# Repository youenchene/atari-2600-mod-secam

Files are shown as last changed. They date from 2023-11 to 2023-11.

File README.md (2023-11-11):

# Atari 2600 Mod SECAM

This project is documentation and gerber files (files to create PCBs) to get SCART SECAM RGB Video Output of your Atari 2600.

No more blury, awful soup of pixels. Welcome clean big early 80's pixel.

## Disclaimer

All credits remains for Mr Eddy works which you can find here : http://eddystoys.blogspot.com/2014/08/atari-2600.html

If you want a ready to use kit you can buy it here :

- PCB Only : https://klydes-korner.site/en/product/convertisseur-video-rgb-atari-2600-secam-pcb-seul/
- Kit to solder : https://klydes-korner.site/en/product/convertisseur-video-rgb-atari-2600-secam-kit/
- Ready To Use : https://klydes-korner.site/en/product/convertisseur-video-rgb-atari-2600-secam/

You also have  CMS version of the PCB from the Modder Brothers : https://gitlab.com/modderbrothers/a2600-secam-rgb

## Before and After

### Before

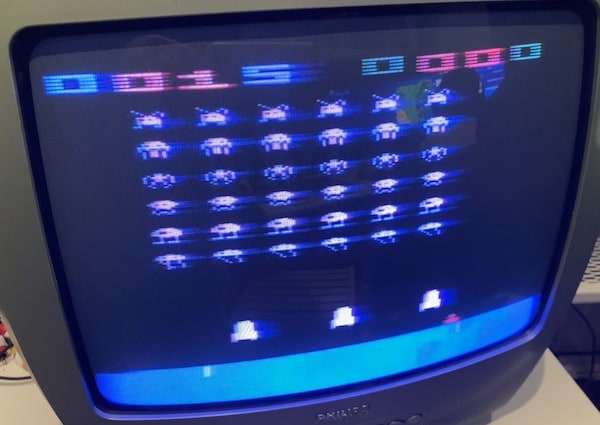
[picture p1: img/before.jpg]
Space Invader, all blury, I want to puke


### After

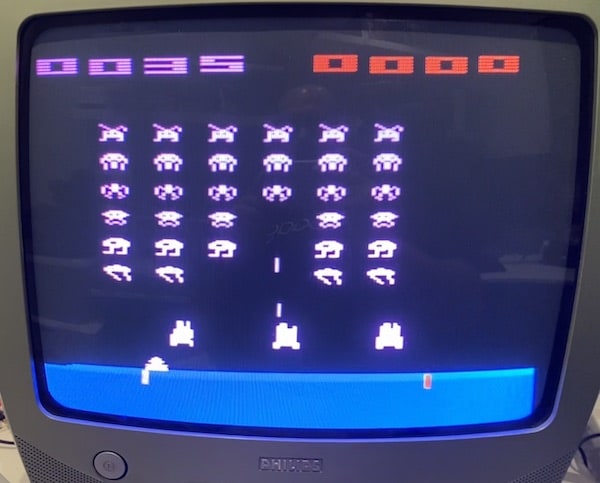
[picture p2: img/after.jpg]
Space Invader, clean pixels, kids let's play!


## Warning

It need soldering on your Atari 2600, I would say it's medium skill soldering, it's not so difficult.

Be aware you can damage your Atari 2600 and it's your responsability.

## How to build

### PCB

Go to PCBWay, Fast PCB, JL PCB or other supplier using this zip file : [gerber/AtariSecam.zip](gerber/AtariSecam.zip).

If your lazy your use my PCBWay project and make your order from here : https://www.pcbway.com/project/shareproject/Atari_2600_Video_Mod_SECAM_857de2b7.html
## Components

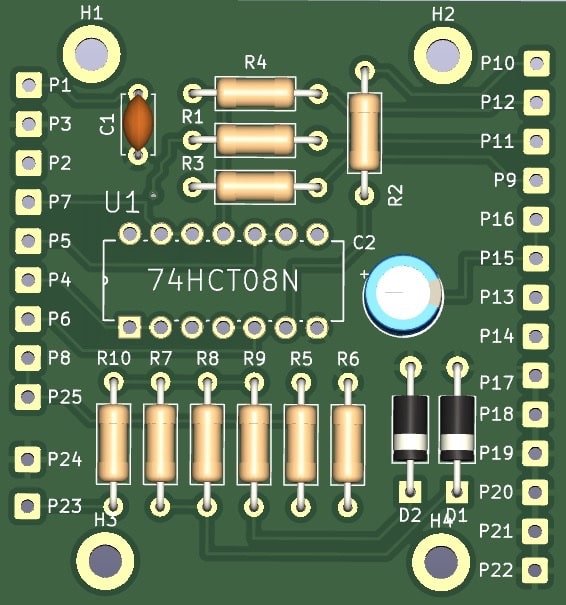
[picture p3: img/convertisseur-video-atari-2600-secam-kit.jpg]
PCB View


| Reference | Value | Qté |
|---|---|---|
| C1 | 100nF | 1 |
| C2 | 47uF | 1 |
| D1 | D_Zener 2.7v | 1 |
| D2 | D_Zener 10v | 1 |
| R1-R4 | 470R | 4 |
| R5, R10 | 1K | 2 |
| R6 | 1k | 1 |
| R7, R8 | 300R | 2 |
| R9 | 200R | 1 |
| U1 | 74HCT08N | 1 |

You also need :
- a scart cable from garage sales or "Foire à tout" like we say in Normandy.
- wiring cable.

## Wiring

### SCART

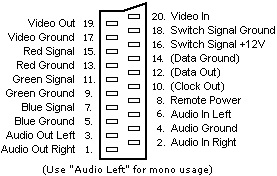
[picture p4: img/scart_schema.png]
SCART Schema SCART Schema


| PCB | SCART |
|---|---|
| P9 | SCART R (15) |
| P10 | SCART G (11) |
| P11 | SCART B (7) |
| P12 | SCART Synchro (20) |
| P13 | SCART Com Slow (8) |
| P14 | SCART Com Fast (16) |
| P15 | SCART Audio R (2) |
| P16 | SCART Audio L (6) |
| P17 | SCART Ground R (13) |
| P18 | SCART Ground G (9) |
| P19 | SCART Ground B (5) |
| P20 | SCART Ground Sync (17) |
| P21 | SCART Ground Audio (4) |
| P22 | SCART Shield (21) |

If you get a male/male scart cable that you cut of beware that the wiring between audio (2,4 - 1,5) and synchro (20-19) is inverted (input to output), always check this is the right pin on the scart you will plug. I lost 2 hours to diagnose and rewire.

### Atari 2600

| Mod PCB | Comments | Atari 2600 PCB |
|---|---|---|
| P1 | +5v | Power regulator Right one - green wire on the photo |
| P2 | +9,5v | Power regulator left one - red wire on the photo |
| P3 | Ground | Power regulator middle one - black wire on the photo |
| P4 | TIA LUM 0 | C0111903/UM6521* (Pal) : 7  <br/>  C01014444D (NTSC) : 2 |
| P5 | TIA LUM 1 | C0111903/UM6521* (Pal) : 5 <br/>  C01014444D (NTSC) : 8 |
| P6 | TIA LUM 2 | C0111903/UM6521* (Pal) : 6 <br/>  C01014444D (NTSC) : 5 |
| P7 | TIA Synchro | C0111903/UM6521* (Pal) : 2 <br/>  C01014444D (NTSC) : 7 |
| P8 | TIA Audio | C0111903/UM6521* (Pal) : 13  <br/>  C01014444D (NTSC) : 13 |
| P25 | Iso potential P8 | Not connected |

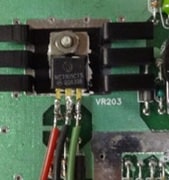
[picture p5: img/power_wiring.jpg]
Wiring for P1, P2, P3, All credits to Mr Eddy


_Wiring for P1, P2, P3, All credits to Mr Eddy_

To identify better the wiring on the Atari 2600 : 

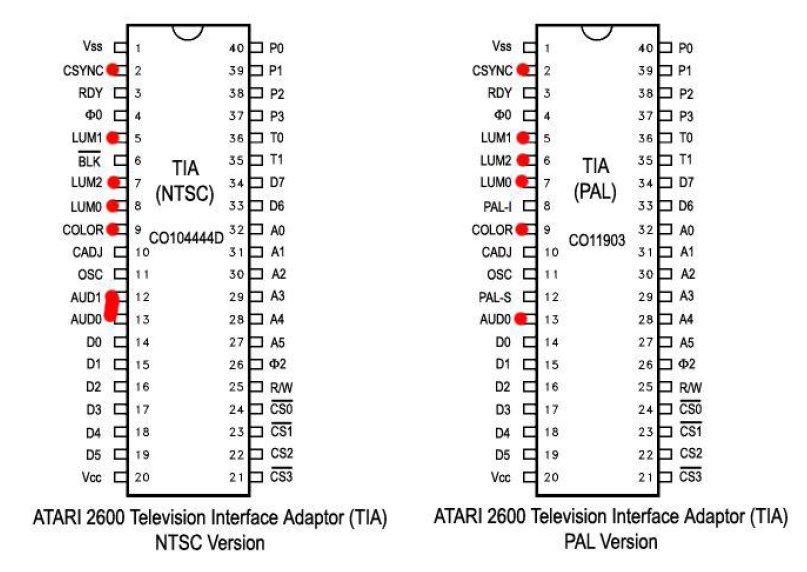
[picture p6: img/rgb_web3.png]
Atari 2600 TIA Wiring, all credits to Mr Eddy

_All credits to Mr Eddy_

Note that the C011903 can have other name, on mine it was an UM6521P1, it exactly the same wiring as the C011903.

On the table, the C01014444D it's the same chip but for NTSC Atari 2600. 

### LED - Optional

Optional, you can plug a 10mA or 20mA LED on P23 and P24.

P23 is + wiring (long pin).

P24 is ground wiring (short pin).

## Video Tutorials

(French) CabriDIY / [Atari 2600] Construction du kit RGB pour Atari 2600 https://youtu.be/S6Wm6l0JoSQ?si=zYLoU-hGtrezSI1l

(French) CabriDIY / [Atari 2600] Installation d'un mod RGB sur une Atari 2600 (prise péritel) https://youtu.be/MnF89gb17LY?si=qCZCWdnxvj2ZiaQF

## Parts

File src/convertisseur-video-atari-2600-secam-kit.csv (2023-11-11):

Reference | Value | Footprint | Datasheet | Availability | Check_prices | Description | MF | MP | MPN | OC_FARNELL | OC_NEWARK | PACKAGE | Package | Price | SUPPLIER | SnapEDA_Link | Qté
C1 | 100nF | Capacitor_THT:C_Disc_D4.7mm_W2.5mm_P5.00mm | ~ |  |  |  |  |  |  |  |  |  |  |  |  |  | 1
C2 | 47uF | Capacitor_THT:CP_Radial_D6.3mm_P2.50mm | ~ |  |  |  |  |  |  |  |  |  |  |  |  |  | 1
D1 | D_Zener 2.7v | Diode_THT:D_A-405_P10.16mm_Horizontal | ~ |  |  |  |  |  |  |  |  |  |  |  |  |  | 1
D2 | D_Zener 10v | Diode_THT:D_A-405_P10.16mm_Horizontal | ~ |  |  |  |  |  |  |  |  |  |  |  |  |  | 1
H1-H4 | MountingHole | MountingHole:MountingHole_2.7mm_M2.5_DIN965_Pad | ~ |  |  |  |  |  |  |  |  |  |  |  |  |  | 4
P1-P8, P23-P25 | Conn_01x01_Pin | Connector_Wire:SolderWire-0.5sqmm_1x01_D0.9mm_OD2.1mm | ~ |  |  |  |  |  |  |  |  |  |  |  |  |  | 11
P9 | SCART R (15) | Connector_Wire:SolderWire-0.5sqmm_1x01_D0.9mm_OD2.1mm | ~ |  |  |  |  |  |  |  |  |  |  |  |  |  | 1
P10 | SCART V (11) | Connector_Wire:SolderWire-0.5sqmm_1x01_D0.9mm_OD2.1mm | ~ |  |  |  |  |  |  |  |  |  |  |  |  |  | 1
P11 | SCART B (7) | Connector_Wire:SolderWire-0.5sqmm_1x01_D0.9mm_OD2.1mm | ~ |  |  |  |  |  |  |  |  |  |  |  |  |  | 1
P12 | SCART Synchro (20) | Connector_Wire:SolderWire-0.5sqmm_1x01_D0.9mm_OD2.1mm | ~ |  |  |  |  |  |  |  |  |  |  |  |  |  | 1
P13 | SCART Com Lente (8) | Connector_Wire:SolderWire-0.5sqmm_1x01_D0.9mm_OD2.1mm | ~ |  |  |  |  |  |  |  |  |  |  |  |  |  | 1
P14 | SCART Com Rapide (16) | Connector_Wire:SolderWire-0.5sqmm_1x01_D0.9mm_OD2.1mm | ~ |  |  |  |  |  |  |  |  |  |  |  |  |  | 1
P15 | SCART_Audio D (2) | Connector_Wire:SolderWire-0.5sqmm_1x01_D0.9mm_OD2.1mm | ~ |  |  |  |  |  |  |  |  |  |  |  |  |  | 1
P16 | SCART Audio G (6) | Connector_Wire:SolderWire-0.5sqmm_1x01_D0.9mm_OD2.1mm | ~ |  |  |  |  |  |  |  |  |  |  |  |  |  | 1
P17 | SCART Masse R (13) | Connector_Wire:SolderWire-0.5sqmm_1x01_D0.9mm_OD2.1mm | ~ |  |  |  |  |  |  |  |  |  |  |  |  |  | 1
P18 | SCART Masse V (9) | Connector_Wire:SolderWire-0.5sqmm_1x01_D0.9mm_OD2.1mm | ~ |  |  |  |  |  |  |  |  |  |  |  |  |  | 1
P19 | SCART Masse B (5) | Connector_Wire:SolderWire-0.5sqmm_1x01_D0.9mm_OD2.1mm | ~ |  |  |  |  |  |  |  |  |  |  |  |  |  | 1
P20 | SCART Masse Sync (17) | Connector_Wire:SolderWire-0.5sqmm_1x01_D0.9mm_OD2.1mm | ~ |  |  |  |  |  |  |  |  |  |  |  |  |  | 1
P21 | SCART Masse Audio | Connector_Wire:SolderWire-0.5sqmm_1x01_D0.9mm_OD2.1mm | ~ |  |  |  |  |  |  |  |  |  |  |  |  |  | 1
P22 | SCART Shield | Connector_Wire:SolderWire-0.5sqmm_1x01_D0.9mm_OD2.1mm | ~ |  |  |  |  |  |  |  |  |  |  |  |  |  | 1
R1-R4 | 470R | Resistor_THT:R_Axial_DIN0207_L6.3mm_D2.5mm_P10.16mm_Horizontal | ~ |  |  |  |  |  |  |  |  |  |  |  |  |  | 4
R5, R10 | 1K | Resistor_THT:R_Axial_DIN0207_L6.3mm_D2.5mm_P10.16mm_Horizontal | ~ |  |  |  |  |  |  |  |  |  |  |  |  |  | 2
R6 | 1k | Resistor_THT:R_Axial_DIN0207_L6.3mm_D2.5mm_P10.16mm_Horizontal | ~ |  |  |  |  |  |  |  |  |  |  |  |  |  | 1
R7, R8 | 300R | Resistor_THT:R_Axial_DIN0207_L6.3mm_D2.5mm_P10.16mm_Horizontal | ~ |  |  |  |  |  |  |  |  |  |  |  |  |  | 2
R9 | 200R | Resistor_THT:R_Axial_DIN0207_L6.3mm_D2.5mm_P10.16mm_Horizontal | ~ |  |  |  |  |  |  |  |  |  |  |  |  |  | 1
U1 | 74HCT08N | LibraryKicadPerso:DIP254P762X420-14 |  | In Stock | https://www.snapeda.com/parts/74HCT08N/Texas+Instruments/view-part/?ref=eda | AND Gate IC 4 Channel - 14-PDIP | Texas Instruments | 74HCT08N | 74HCT08N | 381792 | 07WX3522 | DIP-14 | DIP-14 NXP Semiconductors | None | NXP | https://www.snapeda.com/parts/74HCT08N/Texas+Instruments/view-part/?ref=snap | 1

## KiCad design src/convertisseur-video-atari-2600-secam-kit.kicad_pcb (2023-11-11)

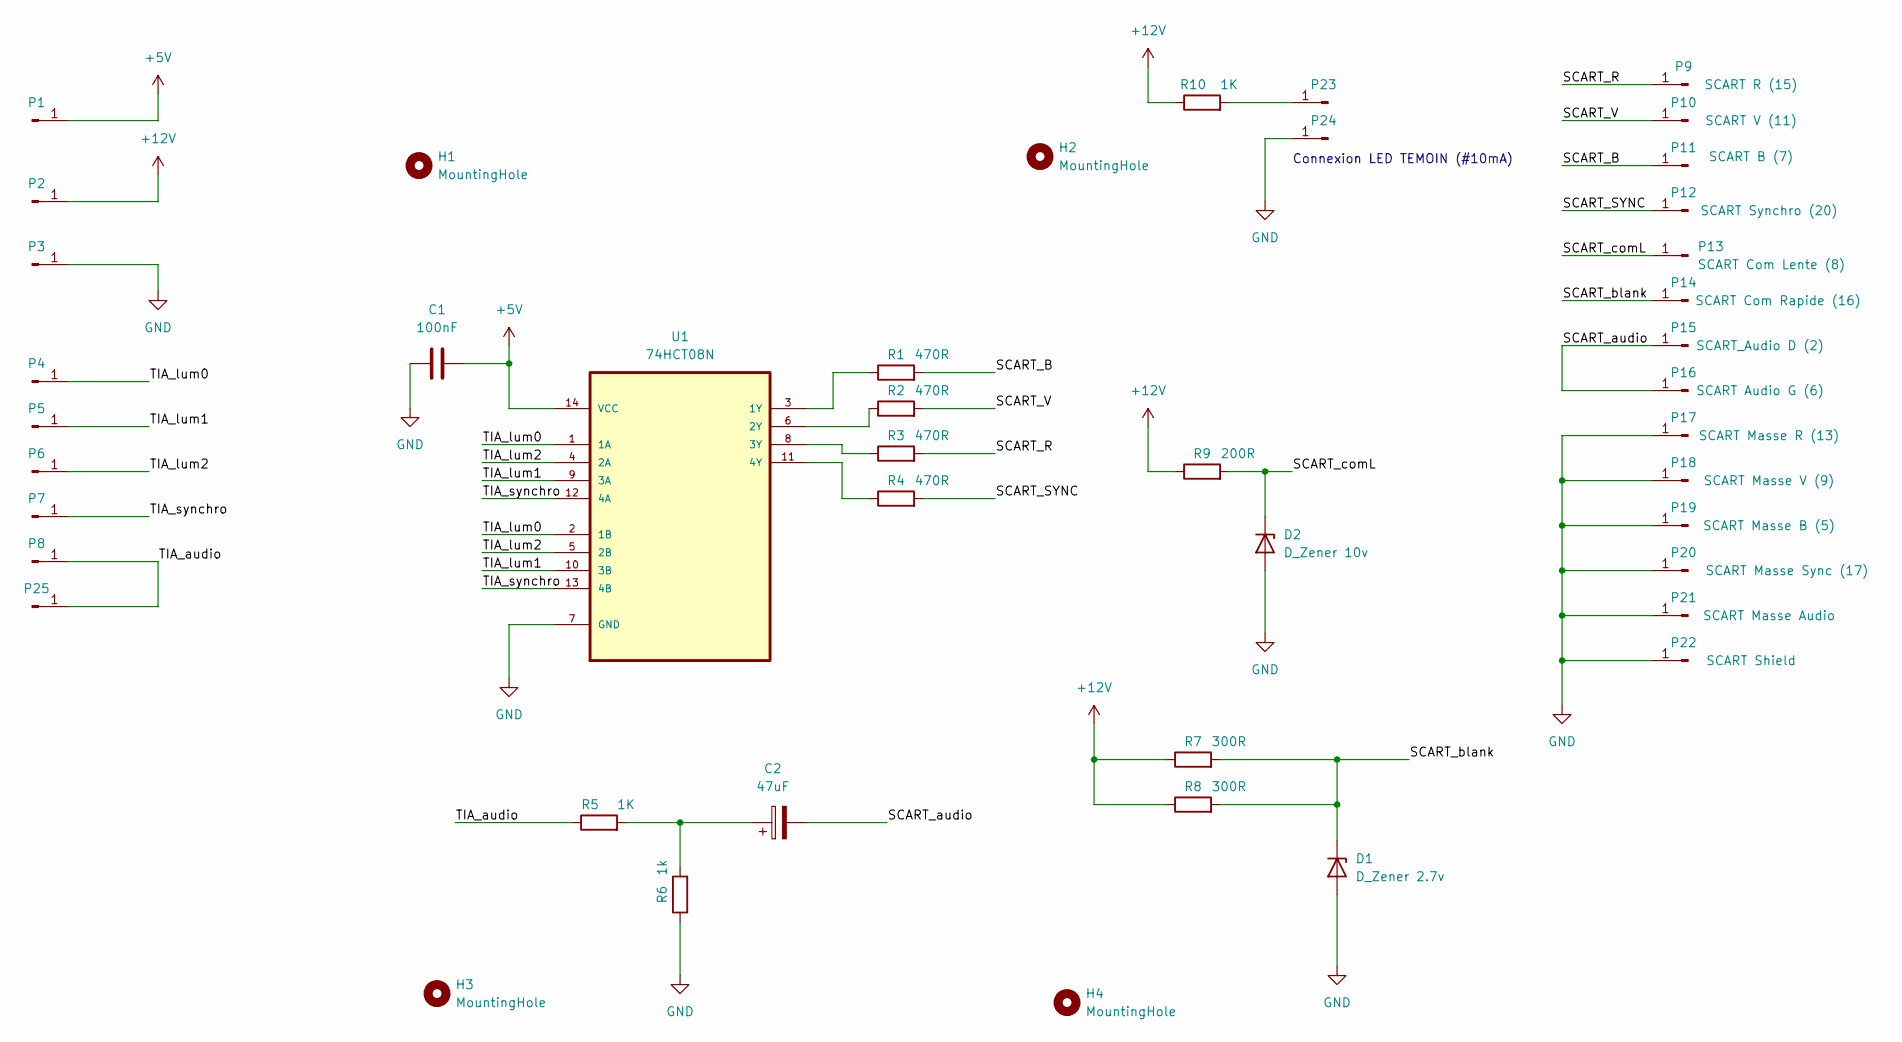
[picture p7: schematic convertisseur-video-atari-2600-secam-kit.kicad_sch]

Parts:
C1: 100nF; C_Disc_D4.7mm_W2.5mm_P5.00mm
C2: 47uF; CP_Radial_D6.3mm_P2.50mm
D1: D_Zener 2.7v; D_A-405_P10.16mm_Horizontal
D2: D_Zener 10v; D_A-405_P10.16mm_Horizontal
H1, H2, H3, H4: MountingHole; MountingHole_2.7mm_M2.5_DIN965_Pad
P1, P2, P3, P4, P5, P6, P7, P8, P23, P24, P25: Conn_01x01_Pin; SolderWire-0.5sqmm_1x01_D0.9mm_OD2.1mm
P9: SCART R (15); SolderWire-0.5sqmm_1x01_D0.9mm_OD2.1mm
P10: SCART V (11); SolderWire-0.5sqmm_1x01_D0.9mm_OD2.1mm
P11: SCART B (7); SolderWire-0.5sqmm_1x01_D0.9mm_OD2.1mm
P12: SCART Synchro (20); SolderWire-0.5sqmm_1x01_D0.9mm_OD2.1mm
P13: SCART Com Lente (8); SolderWire-0.5sqmm_1x01_D0.9mm_OD2.1mm
P14: SCART Com Rapide (16); SolderWire-0.5sqmm_1x01_D0.9mm_OD2.1mm
P15: SCART_Audio D (2); SolderWire-0.5sqmm_1x01_D0.9mm_OD2.1mm
P16: SCART Audio G (6); SolderWire-0.5sqmm_1x01_D0.9mm_OD2.1mm
P17: SCART Masse R (13); SolderWire-0.5sqmm_1x01_D0.9mm_OD2.1mm
P18: SCART Masse V (9); SolderWire-0.5sqmm_1x01_D0.9mm_OD2.1mm
P19: SCART Masse B (5); SolderWire-0.5sqmm_1x01_D0.9mm_OD2.1mm
P20: SCART Masse Sync (17); SolderWire-0.5sqmm_1x01_D0.9mm_OD2.1mm
P21: SCART Masse Audio; SolderWire-0.5sqmm_1x01_D0.9mm_OD2.1mm
P22: SCART Shield; SolderWire-0.5sqmm_1x01_D0.9mm_OD2.1mm
R1, R2, R3, R4: 470R; R_Axial_DIN0207_L6.3mm_D2.5mm_P10.16mm_Horizontal
R5, R10: 1K; R_Axial_DIN0207_L6.3mm_D2.5mm_P10.16mm_Horizontal
R6: 1k; R_Axial_DIN0207_L6.3mm_D2.5mm_P10.16mm_Horizontal
R7, R8: 300R; R_Axial_DIN0207_L6.3mm_D2.5mm_P10.16mm_Horizontal
R9: 200R; R_Axial_DIN0207_L6.3mm_D2.5mm_P10.16mm_Horizontal
U1: 74HCT08N; DIP254P762X420-14; MPN 74HCT08N

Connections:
+5V: C1.2, P1.1, U1.14 (VCC)
+12V: P2.1, R7.1, R8.1, R9.1, R10.1
/SCART_B: P11.1, R1.2
/SCART_R: P9.1, R3.2
/SCART_SYNC: P12.1, R4.2
/SCART_V: P10.1, R2.2
/SCART_audio: C2.2, P15.1, P16.1
/SCART_blank: D1.1 (K), P14.1, R7.2, R8.2
/SCART_comL: D2.1 (K), P13.1, R9.2
/TIA_audio: P8.1, P25.1, R5.1
/TIA_lum0: P4.1, U1.1 (1A), U1.2 (1B)
/TIA_lum1: P5.1, U1.9 (3A), U1.10 (3B)
/TIA_lum2: P6.1, U1.4 (2A), U1.5 (2B)
/TIA_synchro: P7.1, U1.12 (4A), U1.13 (4B)
GND: C1.1, D1.2 (A), D2.2 (A), P3.1, P17.1, P18.1, P19.1, P20.1, P21.1, P22.1, P24.1, R6.1, U1.7 (GND)
unnamed: C2.1, R5.2, R6.2
unnamed: P23.1, R10.2
unnamed: R1.1, U1.3 (1Y)
unnamed: R2.1, U1.6 (2Y)
unnamed: R3.1, U1.8 (3Y)
unnamed: R4.1, U1.11 (4Y)

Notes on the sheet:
Connexion LED TEMOIN (#10mA)

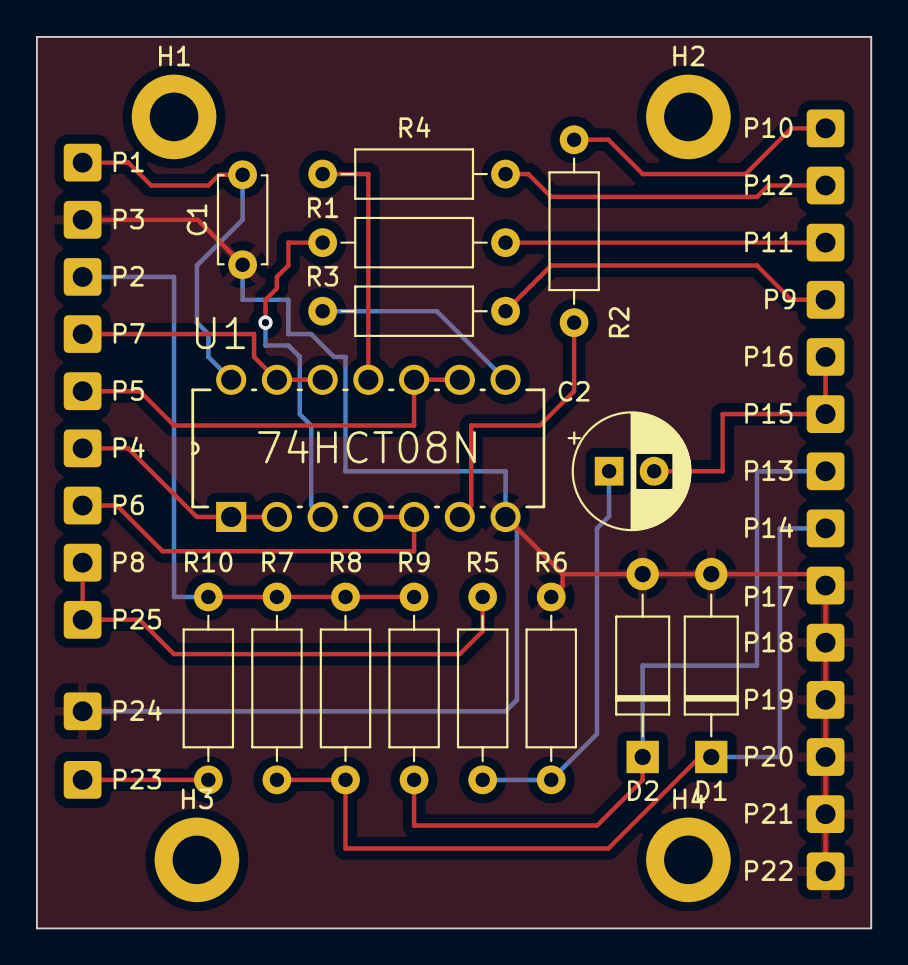
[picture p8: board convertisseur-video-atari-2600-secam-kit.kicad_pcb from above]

Board: 2 copper layers, 46.4 x 49.5 mm, 44 parts (0 on the bottom side), 21 nets.

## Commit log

2023-11-11 feat: Init commit
    [convertisseur-video-atari-2600-secam-kit-B_Cu.gbr, convertisseur-video-atari-2600-secam-kit-B_Mask.gbr, convertisseur-video-atari-2600-secam-kit-B_Paste.gbr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]
2023-11-11 doc: add pcb project link
